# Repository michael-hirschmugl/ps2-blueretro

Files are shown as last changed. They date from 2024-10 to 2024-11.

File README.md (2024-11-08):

# PS2 BlueRetro Mod - BlueMoogle

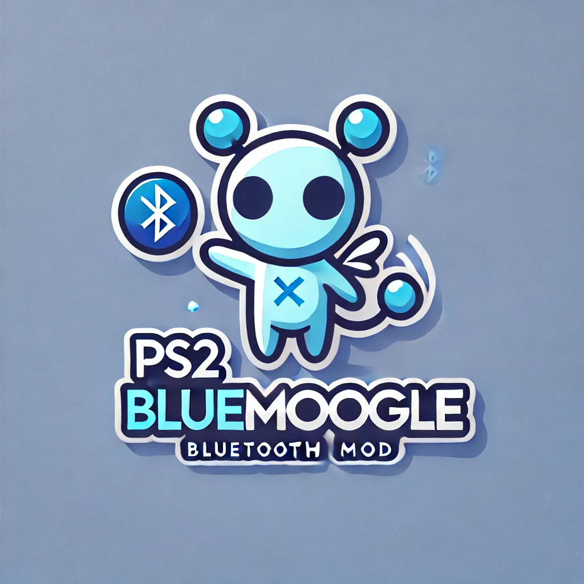
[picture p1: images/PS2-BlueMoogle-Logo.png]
PS2 BlueMoogle Bluetooth Mod Logo


This project adds Bluetooth connectivity for PlayStation 2 controllers, based on the BlueRetro project. The goal is to integrate this functionality directly into the PlayStation 2 as a hardware mod.

## Project Status

The project is currently in the **Prototype v1** phase, with the initial PCB design sent for manufacturing. This version serves to validate core functionalities, including:

- USB-C connection to the ESP32 (tested and working)
- Bluetooth pairing with controllers (tested successfully with a PS3 controller)
- Power supply circuits
- Global status LED
- Controller Port 1 detect LED
- Current mirror for controller detection (working; not tested with real controller)
- Detection of the PlayStation 2 console's power supply

### Future Development

The next steps, after testing Prototype v1, include:

- Connecting the board to Controller Port 1 on the PlayStation 2 and adding support for an optional external controller.
- Expanding the setup to Controller Port 2.
- Minimizing the hardware for integration within a PlayStation 2 Slim.
- Adjusting the firmware as needed based on test results.

### Hardware Version

This project modifies the [BlueRetro HW2](https://github.com/darthcloud/BlueRetro/wiki#2---building-hardware-hw2) design, adapted for integration as a PlayStation 2 mod with external controller detection capabilities.

## Firmware

Currently, the firmware is based on [BlueRetro](https://github.com/darthcloud/BlueRetro). No firmware is included in this repository at this time, but custom modifications may be made to accommodate the unique hardware setup.

### Flashing Instructions

To flash the firmware, follow these steps:

1. Install the USB UART bridge driver if necessary (available through Windows Update).
2. Press and hold the boot button on the board.
3. Briefly press the EN (Reset) button while still holding the boot button.
4. Continue holding the boot button for a moment longer, then release.

> Note: The boot button must be pressed when the board powers on or resets to enable flashing.

For detailed flashing instructions, refer to [Flashing Firmware on Windows 10](https://github.com/darthcloud/BlueRetro/wiki/Flashing-firmware-Windows-10). This guide provides important memory area configurations.

The latest firmware binary can be downloaded here: [BlueRetro Firmware](https://darthcloud.itch.io/blueretro). For this prototype, the **HW1 Universal** firmware was used.

## Controller Pairing

To pair a PS3 controller, follow the [PS3 Pairing Guide](https://github.com/darthcloud/BlueRetro/wiki/Controller-pairing-guide#2---ps3-pairing-guide). The **Sixaxis Pair Tool** is required to set the Bluetooth master for the controller. Download it here: [Sixaxis Pair Tool](https://sixaxispairtool.en.lo4d.com/windows#:~:text=The%20Sixaxis%20Pair%20Tool%20is,games%20with%20your%20PS3%20controller).

The Bluetooth MAC address of the BlueRetro board can be located in the advanced settings of the web configuration.

### BlueRetro Web Configuration

To access BlueRetro’s web configuration, a BLE-enabled Bluetooth adapter is required. You can access it here: [BlueRetro WebConfig](https://blueretro.io/).

For Brave browser users: Bluetooth web configuration may need to be enabled in the settings under `brave://flags`.

## Next Steps

1. Test and validate Prototype v1 functionality.
2. Adapt the hardware for PlayStation 2 Controller Port 2.
3. Shrink the hardware for PlayStation 2 Slim compatibility.
4. Continue with firmware development and testing.
5. Prepare for Prototype v2.

## Acknowledgments

This project is based on the [BlueRetro project](https://github.com/darthcloud/BlueRetro), which provides the foundation for Bluetooth connectivity with classic gaming consoles.

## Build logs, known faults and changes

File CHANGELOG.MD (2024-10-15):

# Changelog

## [Unreleased]

### Added
- Initial prototype PCB (v1) for testing:
  - USB-C connection to ESP32
  - Bluetooth connection to controllers
  - Power supplies, status LEDs, controller detection

### Planned
- Finalize pin assignments
- Test prototype with PlayStation 2 console
- Design next prototype (v2) with Controller Port 2 support
- Shrink hardware for PlayStation 2 Slim compatibility
- Adapt BlueRetro firmware for custom hardware design

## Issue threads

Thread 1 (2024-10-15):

Test USB-C connection to ESP32

michael-hirschmugl, 2024-10-15:
**Description**: Test the USB-C connection between the PS2 BlueRetro mod PCB and the ESP32 to ensure proper power delivery and data transfer.

**Acceptance Criteria**:
- USB-C connection provides power to the ESP32.
- Data connection is functional.

**Priority**: High
**Labels**: `hardware`, `testing`
**Milestone**: Prototype v1

michael-hirschmugl, 2024-10-29:
Had to remove /SUPSEND pull-down resistor and swap RXD and TXD. Working now.

Closed 2024-10-29.

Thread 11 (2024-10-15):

Finalize component values for Prototype v1

michael-hirschmugl, 2024-10-15:
**Description**: Define and finalize the component values for the Prototype v1 PCB. This includes resistors, capacitors, and other passive components to ensure proper functionality during testing.

**Acceptance Criteria**:
- All component values are reviewed and finalized.
- Updated schematic includes finalized component values.
- Documentation of changes is updated.

**Priority**: High
**Labels**: `hardware`, `prototype`, `component-definitions`
**Milestone**: Prototype v1

Closed 2024-11-20.

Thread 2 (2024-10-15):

Test Bluetooth connection with controllers

michael-hirschmugl, 2024-10-15:
**Description**: Verify that the Bluetooth module on the ESP32 can successfully connect to PlayStation 2 controllers.

**Acceptance Criteria**:
- Controller pairs and communicates with the ESP32.
- Input from the controller is detected by the system.

**Priority**: High
**Labels**: `firmware`, `testing`
**Milestone**: Prototype v1

michael-hirschmugl, 2024-11-04:
Working.

Closed 2024-11-04.

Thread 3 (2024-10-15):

Validate all power supplies

michael-hirschmugl, 2024-10-15:
**Description**: Ensure that all power supplies on the PCB function correctly.

**Acceptance Criteria**:
- Correct voltage levels are present at each power pin.
- No overheating or power instability.

**Priority**: Medium
**Labels**: `hardware`, `testing`
**Milestone**: Prototype v1

Closed 2024-10-29.

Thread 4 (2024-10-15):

Test global status LED

michael-hirschmugl, 2024-10-15:
**Description**: Verify that the global status LED shows the correct system status.

**Acceptance Criteria**:
- LED lights up when the system is powered.
- LED blinks or changes color based on system status (e.g., Bluetooth pairing, connection, errors).

**Priority**: Medium
**Labels**: `hardware`, `testing`
**Milestone**: Prototype v1

michael-hirschmugl, 2024-11-05:
I need to find a good value for the resistor.

michael-hirschmugl, 2024-11-11:
working. resistor values are just 1k and 1k.

Closed 2024-11-11.

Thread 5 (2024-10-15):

Test Controller Port 1 detect LED

michael-hirschmugl, 2024-10-15:
**Description**: Ensure that the LED for detecting a controller on Port 1 works correctly.

**Acceptance Criteria**:
- LED lights up when a controller is detected on Port 1.

**Priority**: Medium
**Labels**: `hardware`, `testing`
**Milestone**: Prototype v1

Closed 2024-11-20.

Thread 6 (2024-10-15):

Test current mirror for controller detection

michael-hirschmugl, 2024-10-15:
**Description**: Test the current mirror circuit to verify correct detection of a connected controller on Port 1.

**Acceptance Criteria**:
- Current mirror outputs the correct signal when a controller is connected.

**Priority**: High
**Labels**: `hardware`, `testing`
**Milestone**: Prototype v1

michael-hirschmugl, 2024-11-05:
I have to modify the supply of the BSS138 transistor to 3.3V. Otherwise, the output could exceed 3.3V and damage the ESP32.

michael-hirschmugl, 2024-11-11:
working. defined in pcb-testing.

Closed 2024-11-11.

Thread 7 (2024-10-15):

Finalize pin definitions for Prototype v1

michael-hirschmugl, 2024-10-15:
**Description**: Finalize and document all pin assignments for the components on the Prototype v1 PCB.

**Acceptance Criteria**:
- All pins are defined and documented in the project files.
- Pin assignments do not conflict with each other or interfere with functionality.

**Priority**: High
**Labels**: `hardware`, `pin-definitions`
**Milestone**: Prototype v1

michael-hirschmugl, 2024-11-05:
For this, I will have to design another prototype that can also connect to controller ports and to a PS2. Some pins can be defined differently, but some just like this.

Closed 2024-11-20.

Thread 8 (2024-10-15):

Design next prototype with Controller Port 2 support

michael-hirschmugl, 2024-10-15:
**Description**: Modify the PCB design to support PlayStation 2 Controller Port 2.

**Acceptance Criteria**:
- Schematic and PCB layout are updated to include Controller Port 2.
- Power and signal paths are correctly routed.

**Priority**: Medium
**Labels**: `hardware`, `design`
**Milestone**: Prototype v2

Closed 2024-12-09.

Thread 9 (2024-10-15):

Shrink hardware for PlayStation 2 Slim compatibility

michael-hirschmugl, 2024-10-15:
**Description**: Redesign the PCB to fit inside the PlayStation 2 Slim.

**Acceptance Criteria**:
- PCB dimensions are reduced to fit within the PS2 Slim enclosure.
- All components and connections remain functional.

**Priority**: Low
**Labels**: `hardware`, `design`
**Milestone**: Prototype v2

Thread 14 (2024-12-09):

Isolate Pin 5 and Pad 5 on Controller Ports 1 and 2

michael-hirschmugl, 2024-12-09:
Attempt to separate Pin 5 and Pad 5 by carefully desoldering the connection. After separation, use UV paste to insulate the pad to prevent any unintended connections. Perform this procedure on both Controller Port 1 and Controller Port 2.

1. Carefully desolder the connection between Pin 5 and Pad 5 on Controller Port 1.
2. Apply UV paste to isolate Pad 5.
3. Repeat the same procedure for Controller Port 2.
4. Verify the isolation using a multimeter to ensure no electrical connection remains between Pin 5 and Pad 5.

Closed 2024-12-11.

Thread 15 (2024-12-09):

Install Prototyping Board and Connect to PlayStation 2 Motherboard

michael-hirschmugl, 2024-12-09:
Integrate the prototyping board into the development system and connect it to the PlayStation 2 motherboard. This involves soldering cables for the controller pins, the reset signal, and the 8.5V DC power supply.

1. Mount the prototyping board into the development system.
2. Solder cables for the controller pins to ensure proper connections with the PlayStation 2 motherboard.
3. Connect the reset signal to the appropriate pin on the PlayStation 2 motherboard.
4. Solder and connect the 8.5V DC power supply to provide necessary power.
5. Double-check all connections for continuity and correct placement.

Closed 2024-12-11.

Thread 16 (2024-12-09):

Test Functions with Custom Firmware

michael-hirschmugl, 2024-12-09:
Test the functionality of the prototyping board using a custom firmware, which will be stored under the `pcb-testing` branch. The firmware should:
- Read inputs and output the values to the monitoring system.
- Activate all outputs and play a signal on the piezo buzzer.
- Periodically toggle the reset input buffer and forward the reset signal while a specific LED is illuminated.

Ensure that the prototyping board is fully connected to the PlayStation 2 motherboard before testing.

### Steps:
1. Develop a custom firmware to:
   - Read and display inputs via the monitoring system.
   - Operate all outputs and play a sound using the piezo buzzer.
   - Periodically toggle the reset input buffer and ensure the reset signal is forwarded while a designated LED is on.
2. Flash the firmware to the prototyping board.
3. Verify that all inputs and outputs behave as expected in the monitoring system.
4. Test the reset buffer functionality:
   - Observe the periodic on/off toggling.
   - Confirm that the reset signal is forwarded only when the designated LED is on.
5. Document the results of each test, noting any irregularities.

Closed 2024-12-11.

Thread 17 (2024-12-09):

Test Original Firmware

michael-hirschmugl, 2024-12-09:
Test the original firmware on the prototyping board after ensuring all hardware and the development system are fully operational. This requires the board to be soldered to the PlayStation 2 motherboard and all connections verified. Once the development system and hardware are confirmed functional, proceed to test the original firmware, potentially using a PS4 controller. Additionally, use the PlayStation version of the firmware for hardware version 2 and modify it slightly (reset handling and buzzer feedback).

### Steps:
1. Solder the prototyping board to the PlayStation 2 motherboard.
2. Verify that all hardware functions and connections are operational, including:
   - Development system.
   - Inputs, outputs, and power supply.
3. Load the original firmware onto the prototyping board.
4. Perform initial functionality tests of the firmware:
   - Confirm basic operations with the development system.
   - If needed, connect a PS4 controller for further testing.
5. Use the PlayStation version of the firmware for hardware version 2.
6. Modify the firmware to include:
   - Proper reset handling.
   - Feedback through the buzzer.
7. Test the modified firmware and document results.

### Notes:
- Ensure all components are operational before testing the firmware.
- Be prepared to troubleshoot and iterate based on test results.

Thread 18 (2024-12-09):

Replace Improvised Components with Correct Parts

michael-hirschmugl, 2024-12-09:
### Description:
Replace the temporarily soldered components on the prototyping board with the correct parts to ensure proper functionality and reliability.

### Steps:
1. Identify the improvised components on the prototyping board.
2. Carefully desolder the temporary components.
3. Solder the correct parts in place.
4. Verify the connections and functionality of the replaced components.

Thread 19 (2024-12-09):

Solder Remaining Missing Components

michael-hirschmugl, 2024-12-09:
### Description:
Complete the prototyping board assembly by soldering all remaining missing components to ensure full functionality.

### Steps:
1. Identify the missing components on the prototyping board.
2. Solder the missing components in their designated positions.
3. Inspect and verify all solder joints.
4. Test the board to confirm functionality after completion.

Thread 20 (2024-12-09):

Connect Clock Input for PAL SNES

michael-hirschmugl, 2024-12-09:
### Description:
Retrieve the clock input for the PAL SNES directly from the motherboard and ensure proper connection to the prototyping board.

### Steps:
1. Identify the clock input source on the PAL SNES motherboard.
2. Solder a connection from the clock input to the appropriate pin on the prototyping board.
3. Verify the clock signal integrity using an oscilloscope or multimeter.
4. Ensure the connection does not interfere with other motherboard functionalities.

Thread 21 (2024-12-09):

Complete Development System Build

michael-hirschmugl, 2024-12-09:
### Description:
Assemble and finalize the development system to support testing and integration of the prototyping board.

### Steps:
1. Gather all necessary components for the development system.
2. Assemble the components into a functional setup.
3. Verify all subsystems (power, inputs, outputs) are operational.
4. Ensure the system is ready for integration with the prototyping board.

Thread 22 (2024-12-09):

Install Prototyping Board into Development System

michael-hirschmugl, 2024-12-09:
### Description:
Integrate the prototyping board into the finalized development system to prepare for testing and debugging.

### Steps:
1. Place the prototyping board into the designated slot or area within the development system.
2. Secure the board to prevent movement during testing.
3. Connect all necessary interfaces (e.g., power, inputs, outputs, clock).
4. Verify that the prototyping board is correctly integrated and powered.
5. Perform initial functionality checks.

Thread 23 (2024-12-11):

Correctly Dimension Controller Port Detection Circuitry

michael-hirschmugl, 2024-12-11:
- **Description**: Adjust the resistor in the current mirror to enable accurate detection of a wired controller being connected. Test and validate the updated circuitry.
- **Acceptance Criteria**:
  1. The circuit detects when a wired controller is connected.
  2. The detection signal is stable and reproducible under various test conditions.
  3. The circuit behaves as expected according to simulation results.

michael-hirschmugl, 2024-12-15:
Nostalgic Indulgence uses YJS2301A transistor: https://github.com/nostalgic-indulgences/BlueRetro_Internal_Installation

michael-hirschmugl, 2024-12-15:
I cannot find this transistor. But it's still odd, that I cannot get this circuit to work even though I use the same components as recommended by mancloud.

michael-hirschmugl, 2024-12-15:
I should just use a low offset, single supply, rail-to-rail operational amplifier and a shunt.
If I want to detect 1mA with a 10 Ohm shunt, I just need an amplification of 330. Or maybe a voltage regulator that produces 4V and use this as supply for the controllers.

michael-hirschmugl, 2025-01-31:
There are current sense ICs exactly for this purpose.

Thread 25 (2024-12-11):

Produce First Production Sample Using Flex PCB

michael-hirschmugl, 2024-12-11:
- **Description**: Design and manufacture a flex PCB that integrates Prototype v2 functionality into the PlayStation 2 console, targeting direct integration.
- **Acceptance Criteria**:
  1. The flex PCB is designed and manufactured successfully.
  2. The PCB fits within the console and connects to all required ports and signals.
  3. The functionality of the production sample is validated through testing.

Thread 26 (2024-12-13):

Update PCB Design to Separate DTR Signal

michael-hirschmugl, 2024-12-13:
**Description:**
Modify the current PCB design to ensure that both ports share the TXD, RXD, SCK, and DSR signals, while the DTR signal is routed separately for each port. This change aims to improve signal routing and meet the requirements outlined in the installation diagram.

https://github.com/nostalgic-indulgences/BlueRetro_Internal_Installation/blob/main/Sony%20PlayStation/Stage%20II%20-%20HW2%20Port%20Detection%20(Current%20Trigger)/B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

**Acceptance Criteria:**
- The schematic is updated to reflect shared TXD, RXD, SCK, and DSR signals and separate DTR signals for each port.
- The PCB layout is updated to implement the changes in the schematic.
- Design Rule Check (DRC) and Electrical Rule Check (ERC) pass successfully without errors.
- Manufacturing files (Gerber, BOM, etc.) are generated and ready for prototyping.
- Documentation in the repository is updated to explain the changes made.

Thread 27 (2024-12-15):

Understand Reset Behavior and Finalize PCB Design

michael-hirschmugl, 2024-12-15:
Description:
Investigate the reset behavior of the circuit to ensure proper functionality. Create a finalized PCB layout with a buffer included to test the design. Update the pull-up resistor configuration to ensure the buffer is disabled at startup by switching it from a pull-down to a pull-up resistor.

Acceptance Criteria:

Reset behavior is fully understood and documented.
A finalized PCB design is created with a buffer integrated.
The pull-up resistor is correctly configured, replacing the current pull-down resistor.

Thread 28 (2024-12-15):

Define Buzzer Signals for Events (Future Release)

michael-hirschmugl, 2024-12-15:
Description:
Develop a system for generating distinct buzzer signals corresponding to different events. This feature will enhance user feedback but can be implemented in a future release.

Acceptance Criteria:

A list of events requiring distinct buzzer signals is documented.
Signal patterns for each event are defined and tested in a simulation or prototype.

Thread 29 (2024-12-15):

Remove ESD Diodes from PCB Design

michael-hirschmugl, 2024-12-15:
Description:
Update the PCB design by removing the ESD diodes. These components are typically not required in most designs and can be omitted to simplify the layout.

Acceptance Criteria:

All ESD diodes are removed from the PCB design.
PCB schematic and layout are updated accordingly.
Design changes are verified for compatibility and functionality.

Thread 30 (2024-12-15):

Verify Signal Short-Circuiting on Controller Port

michael-hirschmugl, 2024-12-15:
Description:
Measure and confirm whether the majority of signals on the PlayStation 2 controller port are directly short-circuited on the motherboard. This information is critical for ensuring proper circuit design.

Acceptance Criteria:

A comprehensive measurement of signals on the controller port is performed.
Results are documented, specifying which signals are short-circuited on the PlayStation 2 motherboard.

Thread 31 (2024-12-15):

Identify Debugging Interface for Flex PCB

michael-hirschmugl, 2024-12-15:
Description:
Research and select a suitable debugging interface for the Flex PCB. This interface should enable effective testing and debugging during development and troubleshooting phases.

Acceptance Criteria:

At least three potential debugging interfaces are identified and evaluated.
One interface is selected based on compatibility and ease of use.
The selected debugging interface is integrated into the Flex PCB design.

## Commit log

2024-08-04 Altium projected generated.
    [00-ps2-blueretro.SchDoc, ps2-blueretro.PcbDoc, ps2-blueretro.PrjPcb]
2024-08-05 Some parts as a test.
    [00-ps2-blueretro.SchDoc, ps2-blueretro.PcbDoc]
2024-08-13 New parts in submodule.
    [00-ps2-blueretro.SchDoc, ps2-blueretro.PrjPcb]
2024-08-13 New parts added.
    [00-ps2-blueretro.SchDoc, ps2-blueretro.PrjPcb]
2024-10-10 Made some connections.
    [00-ps2-blueretro.SchDoc]
2024-10-10 Added more schematics and a simulation folder.
    [00-ps2-blueretro.SchDoc, 01-ESP32-ps2-blueretro.SchDoc, 02-USB-ps2-blueretro.SchDoc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]
2024-10-11 Modified the USB-C port and some other things. Starting with PCB for development and prototyping.
    [00-ps2-blueretro.SchDoc, 01-ESP32-ps2-blueretro.SchDoc, 02-USB-ps2-blueretro.SchDoc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]
2024-10-14 First order placed.
    [00-ps2-blueretro.SchDoc, 01-ESP32-ps2-blueretro.SchDoc, 04-CTRL1-ps2-blueretro.SchDoc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]
2024-10-15 Moved hardware development into directory hardware.
    [00-ps2-blueretro.SchDoc, 01-ESP32-ps2-blueretro.SchDoc, 02-USB-ps2-blueretro.SchDoc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]
2024-10-15 Moved simulations from sim to simulation and added gitignore for ltspice.
    [00-ps2-blueretro.SchDoc, 01-ESP32-ps2-blueretro.SchDoc, 02-USB-ps2-blueretro.SchDoc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]
2024-11-07 Removed altium library in order to include it as submodule.
    [mycomponents.PcbLib, mycomponents.SchLib]
2024-11-07 Saved project file.
    [ps2-blueretro.PrjPcb]
2024-11-07 Added scripts for branch switching.
